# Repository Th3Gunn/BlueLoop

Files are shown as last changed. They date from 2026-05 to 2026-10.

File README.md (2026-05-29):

BluePill devboard based project - ultra compact guitar loop switcher controlled entirely through MIDI TRS (something like Morningstar ML5R).
Includes 0.96" I2C LCD module, few buttons (only for programming), USB-C for flashing and USB MIDI. 
5 relay controlled loops (relays controlled with 74HC595 bit shift register), and discrete MOSFET input and  output mute circuit.

Future plans are to make completely custom board (without BluePill module) and to create Windows application for preset programming.

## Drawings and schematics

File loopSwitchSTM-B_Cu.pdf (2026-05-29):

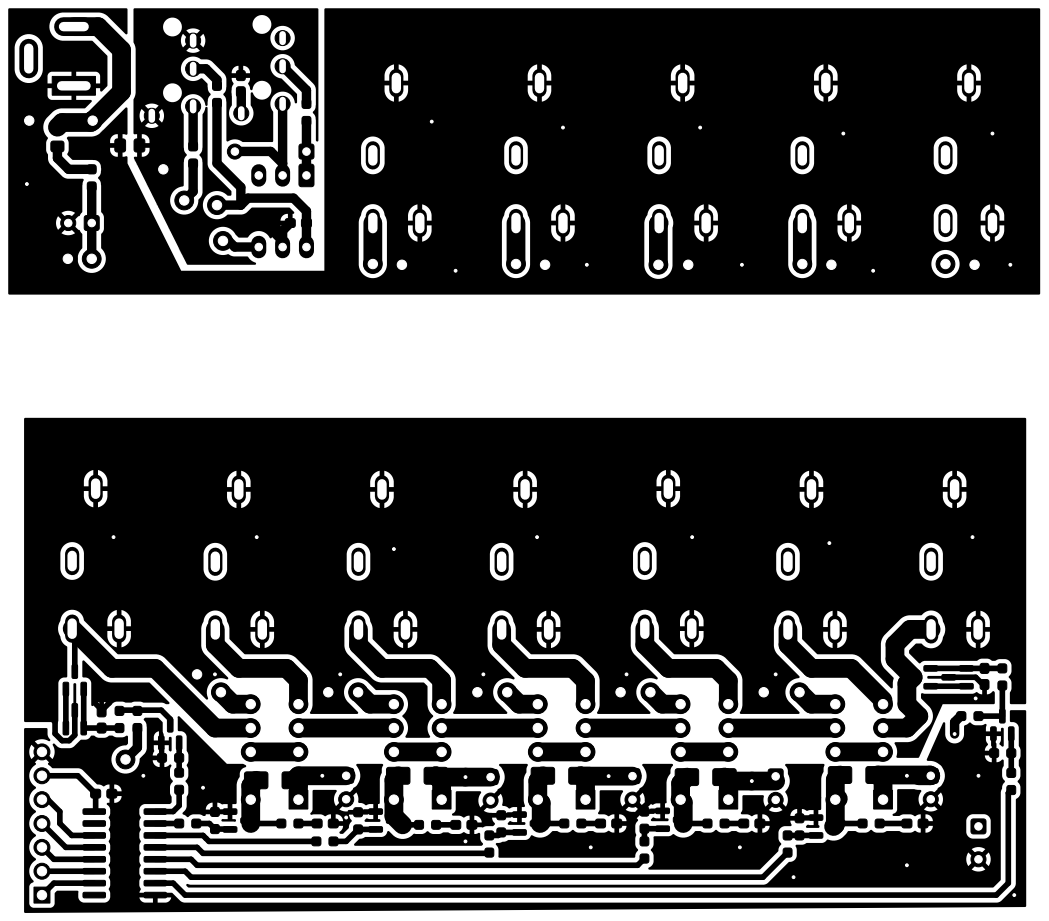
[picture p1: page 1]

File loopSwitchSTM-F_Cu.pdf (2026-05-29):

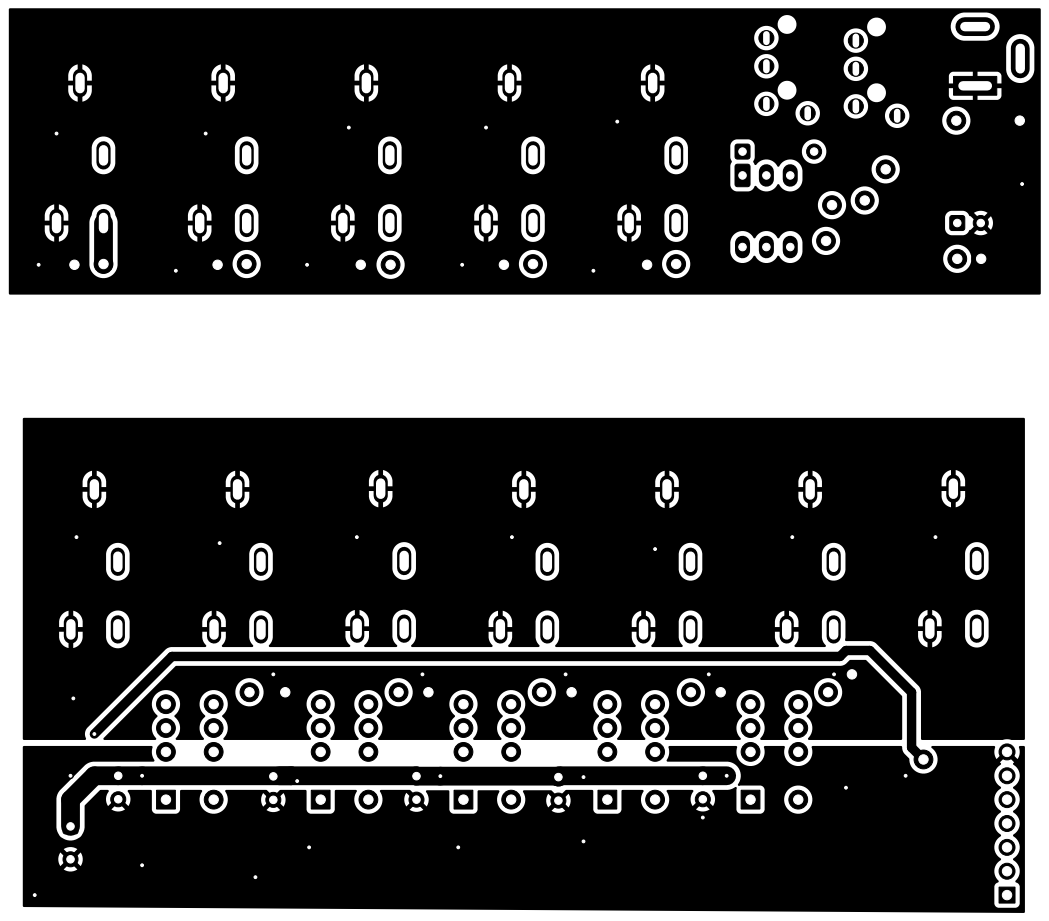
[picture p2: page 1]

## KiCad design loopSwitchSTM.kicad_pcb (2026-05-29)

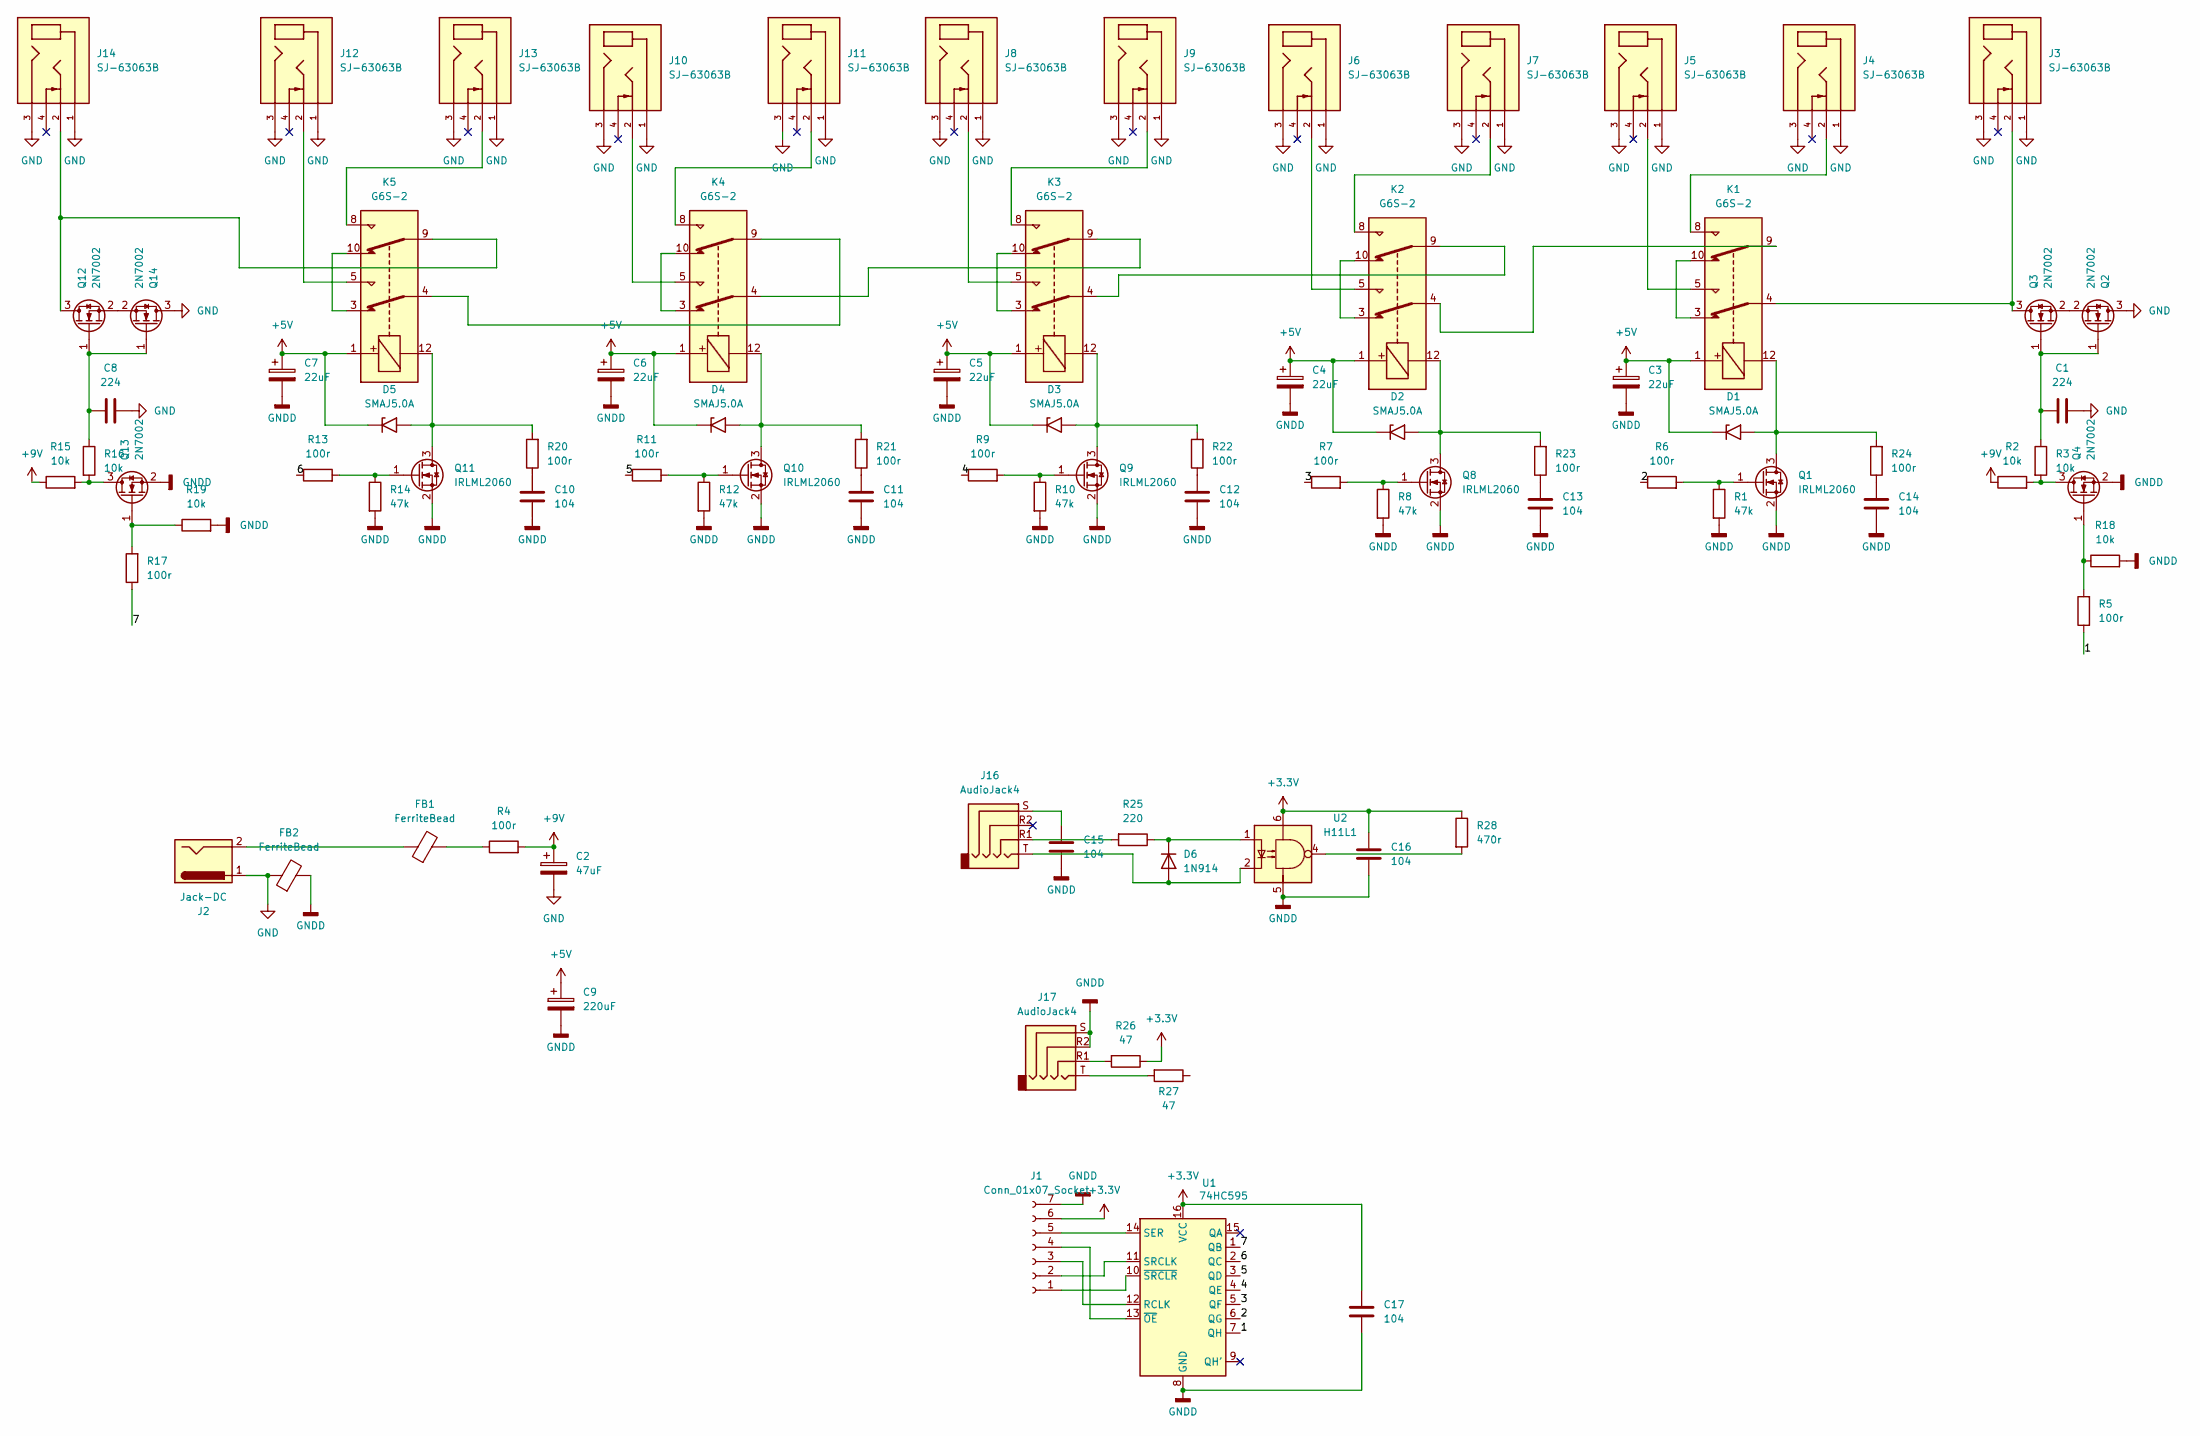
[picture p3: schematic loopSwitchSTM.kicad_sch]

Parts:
C1, C8: 224; C_0603_1608Metric_Pad1.08x0.95mm_HandSolder
C2: 47uF; CP_Radial_D5.0mm_P2.50mm
C3, C4, C5, C6, C7: 22uF; CP_Radial_D5.0mm_P2.50mm
C9: 220uF; CP_Radial_D8.0mm_P3.50mm
C10, C11, C12, C13, C14, C15, C16, C17: 104; C_0603_1608Metric_Pad1.08x0.95mm_HandSolder
D1, D2, D3, D4, D5: SMAJ5.0A; D_SMA
D6: 1N914; D_DO-35_SOD27_P7.62mm_Horizontal
FB1, FB2: FerriteBead; L_0805_2012Metric_Pad1.15x1.40mm_HandSolder
J1: Conn_01x07_Socket; PinHeader_1x07_P2.54mm_Vertical
J2: Jack-DC; BarrelJack_GCT_DCJ200-10-A_Horizontal
J3, J4, J5, J6, J7, J8, J9, J10, J11, J12, J13, J14: SJ-63063B; CUI_SJ-63063B; PARTREV 1.0
J16, J17: AudioJack4; PJ-320A
K1, K2, K3, K4, K5: G6S-2; Relay_DPDT_Omron_G6S-2
Q1, Q8, Q9, Q10, Q11: IRLML2060; SOT-23
Q2, Q3, Q4, Q12, Q13, Q14: 2N7002; SOT-23
R1, R8, R10, R12, R14: 47k; R_0603_1608Metric_Pad0.98x0.95mm_HandSolder
R2, R3, R15, R16, R18, R19: 10k; R_0603_1608Metric_Pad0.98x0.95mm_HandSolder
R4, R5, R6, R7, R9, R11, R13, R17, R20, R21, R22, R23, R24: 100r; R_0603_1608Metric_Pad0.98x0.95mm_HandSolder
R25: 220; R_0603_1608Metric_Pad0.98x0.95mm_HandSolder
R26, R27: 47; R_0603_1608Metric_Pad0.98x0.95mm_HandSolder
R28: 470r
U1: 74HC595; SOIC-16W_5.3x10.2mm_P1.27mm
U2: H11L1; DIP-6_W7.62mm_LongPads

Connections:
+3.3V: C16.2, C17.2, J1.6, R26.1, R28.1, U1.16 (VCC), U2.6
+5V: C3.1, C4.1, C5.1, C6.1, C7.1, C9.1, D1.1 (A1), D2.1 (A1), D3.1 (A1), D4.1 (A1), D5.1 (A1), K1.1, K2.1, K3.1, K4.1, K5.1
+9V: C2.1, R2.1, R4.2, R15.1
/1: R5.1, U1.7 (QH)
/2: R6.1, U1.6 (QG)
/3: R7.1, U1.5 (QF)
/4: R9.1, U1.4 (QE)
/5: R11.1, U1.3 (QD)
/6: R13.1, U1.2 (QC)
/7: R17.1, U1.1 (QB)
GND: C1.2, C2.2, C8.2, FB2.1, J2.1, J3.1, J3.3, J4.1, J4.3, J5.1, J5.3, J6.1, J6.3, J7.1, J7.3, J8.1, J8.3, J9.1, J9.3, J10.1, J10.3, J11.1, J11.3, J12.1, J12.3, J13.1, J13.3, J14.1, J14.3, Q2.3 (D), Q14.3 (D)
GNDD: C3.2, C4.2, C5.2, C6.2, C7.2, C9.2, C10.1, C11.1, C12.1, C13.1, C14.1, C15.1, C16.1, C17.1, FB2.2, J1.7, J17.R2, J17.S, Q1.2 (S), Q4.2 (S), Q8.2 (S), Q9.2 (S), Q10.2 (S), Q11.2 (S), Q13.2 (S), R1.2, R8.2, R10.2, R12.2, R14.2, R18.2, R19.2, U1.8 (GND), U2.5
unnamed: C10.2, R20.1
unnamed: C11.2, R21.1
unnamed: C12.2, R22.1
unnamed: C13.2, R23.1
unnamed: C14.2, R24.1
unnamed: C15.2, J16.S
unnamed: D1.2 (A2), K1.12, Q1.3 (D), R24.2
unnamed: D2.2 (A2), K2.12, Q8.3 (D), R23.2
unnamed: D3.2 (A2), K3.12, Q9.3 (D), R22.2
unnamed: D4.2 (A2), K4.12, Q10.3 (D), R21.2
unnamed: D5.2 (A2), K5.12, Q11.3 (D), R20.2
unnamed: D6.2 (A), J16.T, U2.2
unnamed: D6.1 (K), R25.1, U2.1
unnamed: FB1.1, J2.2
unnamed: FB1.2, R4.1
unnamed: J1.1, U1.10 (~SRCLR)
unnamed: J1.2, U1.11 (SRCLK)
unnamed: J1.3, U1.12 (RCLK)
unnamed: J1.4, U1.13 (~OE)
unnamed: J1.5, U1.14 (SER)
unnamed: J4.2, K1.8
unnamed: J5.2, K1.5
unnamed: J6.2, K2.5
unnamed: J7.2, K2.8
unnamed: J8.2, K3.5
unnamed: J9.2, K3.8
unnamed: J10.2, K4.5
unnamed: J11.2, K4.8
unnamed: J12.2, K5.5
unnamed: J13.2, K5.8
unnamed: J16.R1, R25.2
unnamed: J17.R1, R26.2
unnamed: J17.T, R27.2
unnamed: K1.9, K2.4
unnamed: K1.3, K1.10
unnamed: K2.9, K3.4
unnamed: K2.3, K2.10
unnamed: K3.9, K4.4
unnamed: K3.3, K3.10
unnamed: K4.9, K5.4
unnamed: K4.3, K4.10
unnamed: K5.3, K5.10
unnamed: Q1.1 (G), R1.1, R6.2
unnamed: C1.1, Q2.1 (G), Q3.1 (G), R3.1
unnamed: Q2.2 (S), Q3.2 (S)
unnamed: J3.2, K1.4, Q3.3 (D)
unnamed: Q4.3 (D), R2.2, R3.2
unnamed: Q4.1 (G), R5.2, R18.1
unnamed: Q8.1 (G), R7.2, R8.1
unnamed: Q9.1 (G), R9.2, R10.1
unnamed: Q10.1 (G), R11.2, R12.1
unnamed: Q11.1 (G), R13.2, R14.1
unnamed: J14.2, K5.9, Q12.3 (D)
unnamed: C8.1, Q12.1 (G), Q14.1 (G), R16.1
unnamed: Q12.2 (S), Q14.2 (S)
unnamed: Q13.3 (D), R15.2, R16.2
unnamed: Q13.1 (G), R17.2, R19.1
unnamed: R28.2, U2.4

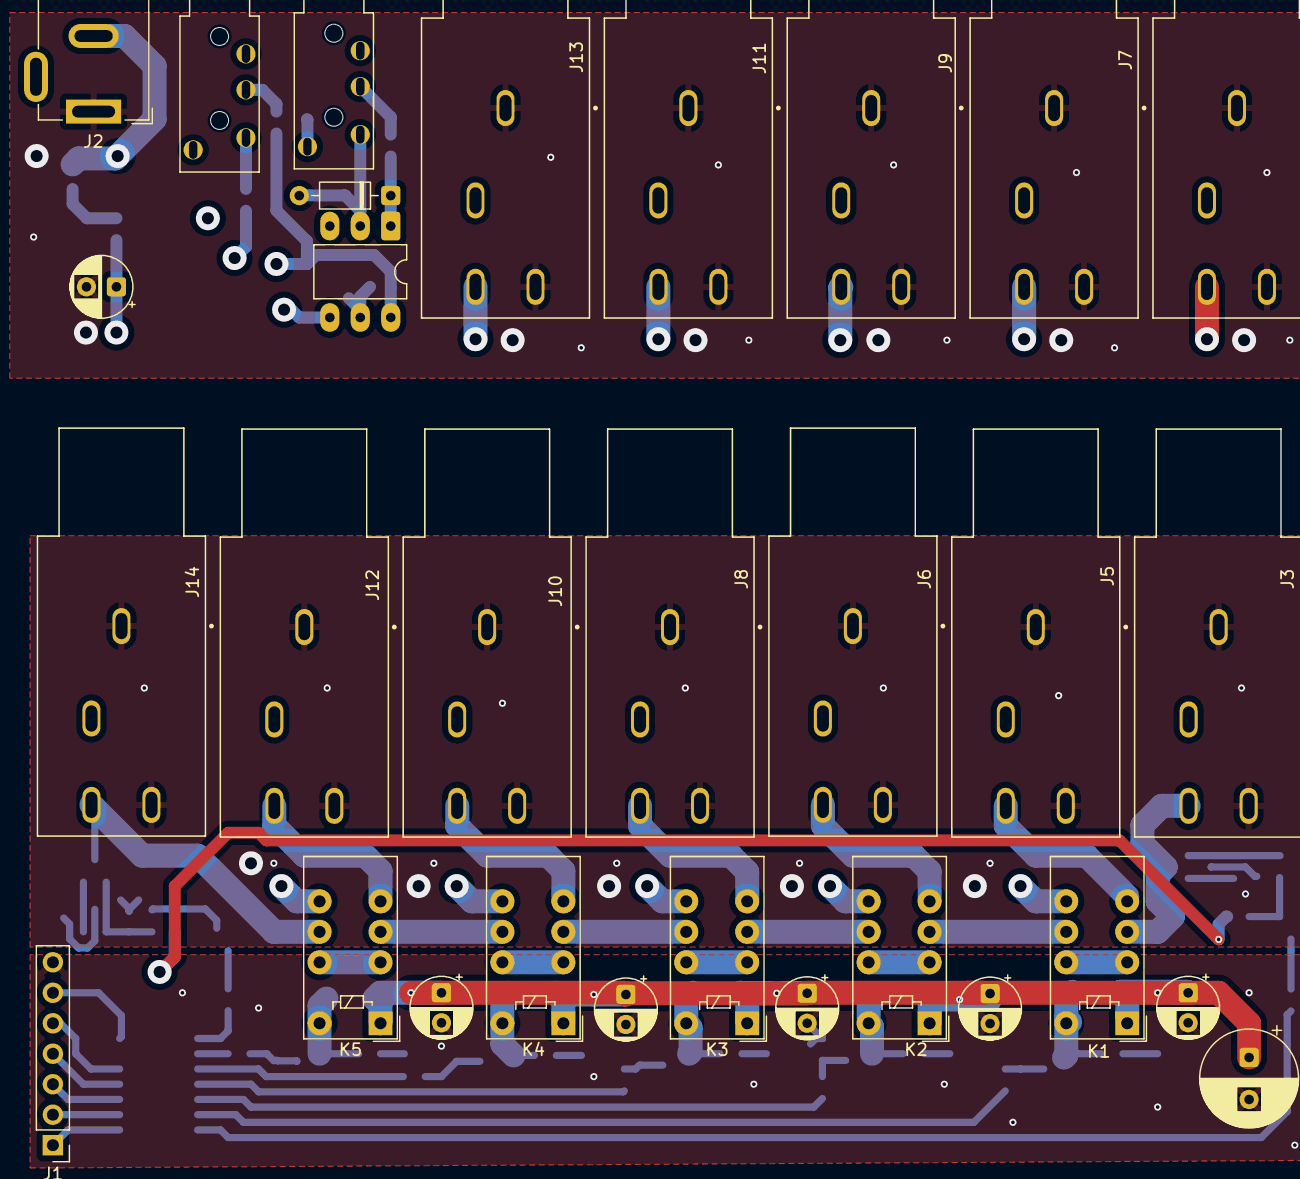
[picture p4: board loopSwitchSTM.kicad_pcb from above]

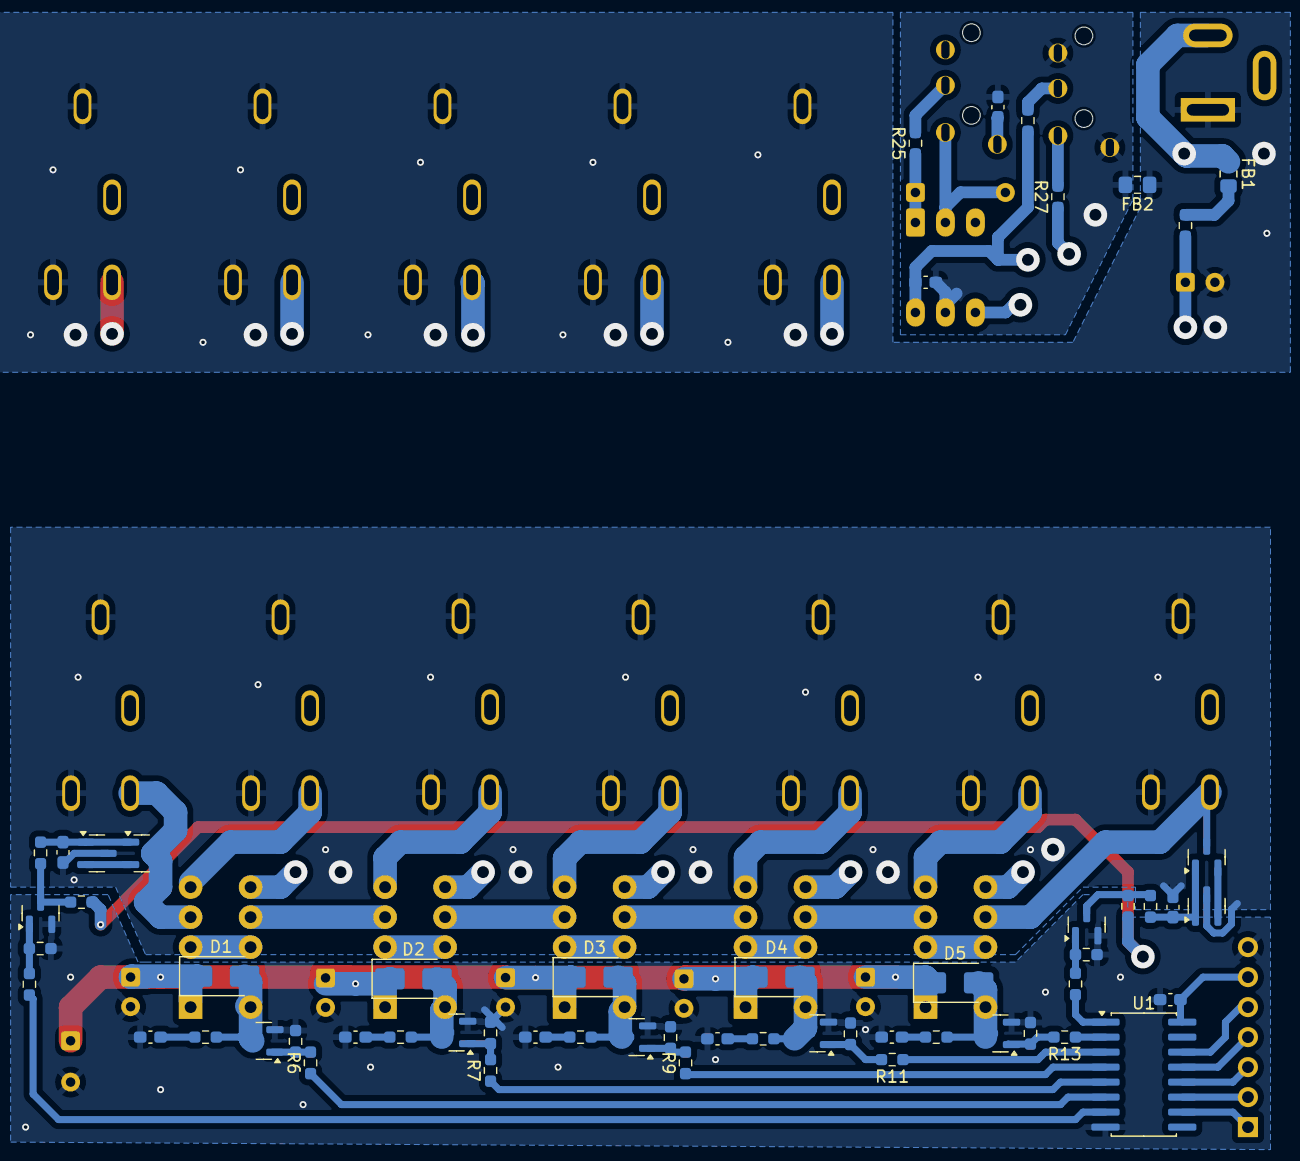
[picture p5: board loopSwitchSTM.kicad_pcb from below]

Board: 2 copper layers, 86 parts (56 on the bottom side), 69 nets.

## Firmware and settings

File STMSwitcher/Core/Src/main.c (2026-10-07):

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
/* Includes ------------------------------------------------------------------*/
#include "main.h"

/* USER CODE BEGIN Includes */
#include <stdio.h>
// NOTE: You must include a standard STM32 HAL SSD1306 library in your project
// (e.g., https://github.com/afaf-buga/stm32-ssd1306)
#include "ssd1306.h"
#include "ssd1306_fonts.h"
/* USER CODE END Includes */

I2C_HandleTypeDef hi2c1;

SPI_HandleTypeDef hspi1;

UART_HandleTypeDef huart1;

PCD_HandleTypeDef hpcd_USB_FS;

/* USER CODE BEGIN PV */
uint8_t midi_rx_byte;
uint8_t current_relay_state = 0x00;
char display_buf[32];
/* USER CODE END PV */

void SystemClock_Config(void);
static void MX_GPIO_Init(void);
static void MX_I2C1_Init(void);
static void MX_SPI1_Init(void);
static void MX_USART1_UART_Init(void);
static void MX_USB_PCD_Init(void);
/* USER CODE BEGIN PFP */
void Update_Relays(uint8_t state);
void MIDI_Process_Byte(uint8_t byte);
/* USER CODE END PFP */

/* USER CODE BEGIN 0 */

/**
 * @brief Sends a byte to the 74HC595 shift register using SPI1
 */
void Update_Relays(uint8_t state)
{
    // Transmit data via SPI (SER -> PA7, SRCLK -> PA5)
    HAL_SPI_Transmit(&hspi1, &state, 1, HAL_MAX_DELAY);

    // Latch the data to the outputs (RCLK -> PA4)
    HAL_GPIO_WritePin(GPIOA, GPIO_PIN_4, GPIO_PIN_SET);
    // Brief delay to ensure latch pin registers high
    for(volatile int i=0; i<100; i++);
    HAL_GPIO_WritePin(GPIOA, GPIO_PIN_4, GPIO_PIN_RESET);
}

/**
 * @brief Basic MIDI parser for Program Change messages
 */
void MIDI_Process_Byte(uint8_t byte)
{
    static uint8_t midi_state = 0;
    static uint8_t status_byte = 0;

    // Check if it's a Status Byte (MSB is 1)
    if (byte >= 0x80)
    {
        status_byte = byte;
        // Check if Program Change (0xCn, where n is channel 0-F)
        if ((status_byte & 0xF0) == 0xC0)
        {
            midi_state = 1; // Expect 1 data byte for PC
        }
        else
        {
            midi_state = 0; // Ignore other messages for now
        }
    }
    // Data byte processing
    else
    {
        if (midi_state == 1 && (status_byte & 0xF0) == 0xC0)
        {
            // Program Change Data Received (Value 0-127)
            current_relay_state = byte;
            Update_Relays(current_relay_state); // Set relays directly to PC value for test

            // Update OLED Display
            ssd1306_Fill(Black);
            ssd1306_SetCursor(2, 10);
            ssd1306_WriteString("MIDI PC Received", Font_7x10, White);

            sprintf(display_buf, "Preset: %d", byte);
            ssd1306_SetCursor(2, 35);
            ssd1306_WriteString(display_buf, Font_11x18, White);
            ssd1306_UpdateScreen();

            midi_state = 0; // Reset state machine
        }
    }
}

/**
 * @brief UART RX Interrupt Callback
 */
void HAL_UART_RxCpltCallback(UART_HandleTypeDef *huart)
{
    if (huart->Instance == USART1)
    {
        // Process incoming MIDI byte
        MIDI_Process_Byte(midi_rx_byte);
        // Start listening for the next byte
        HAL_UART_Receive_IT(&huart1, &midi_rx_byte, 1);
    }
}
/* USER CODE END 0 */

/**
  * @brief  The application entry point.
  * @retval int
  */
int main(void)
{

  /* MCU Configuration--------------------------------------------------------*/

  /* Reset of all peripherals, Initializes the Flash interface and the Systick. */
  HAL_Init();

  /* Configure the system clock */
  SystemClock_Config();

  /* Initialize all configured peripherals */
  MX_GPIO_Init();
  MX_I2C1_Init();
  MX_SPI1_Init();
  MX_USART1_UART_Init();
  MX_USB_PCD_Init();
  /* USER CODE BEGIN 2 */

  // Set default states for 74HC595 control pins
  HAL_GPIO_WritePin(GPIOA, GPIO_PIN_3, GPIO_PIN_SET);   // SRCLR HIGH: Do not clear shift register
  HAL_GPIO_WritePin(GPIOB, GPIO_PIN_0, GPIO_PIN_RESET); // OE LOW: Enable outputs
  HAL_GPIO_WritePin(GPIOA, GPIO_PIN_4, GPIO_PIN_RESET); // RCLK LOW: Default latch state

  // Clear relays on boot
  Update_Relays(0x00);

  // Initialize OLED
  ssd1306_Init();
  ssd1306_Fill(Black);
  ssd1306_SetCursor(10, 20);
  ssd1306_WriteString("MIDI Looper", Font_11x18, White);
  ssd1306_SetCursor(10, 45);
  ssd1306_WriteString("Waiting...", Font_7x10, White);
  ssd1306_UpdateScreen();

  // Start UART Interrupt Reception for MIDI
  HAL_UART_Receive_IT(&huart1, &midi_rx_byte, 1);

  /* USER CODE END 2 */

  /* Infinite loop */
  /* USER CODE BEGIN WHILE */
  while (1)
  {
    /* USER CODE END WHILE */

    /* USER CODE BEGIN 3 */

    /*
     * --- UNCOMMENT THIS BLOCK TO TEST RELAYS & OLED WITHOUT MIDI ---
     * Cycles through relays one by one every 1 second
     */

    /*
    static uint8_t test_val = 1;
    Update_Relays(test_val);

    sprintf(display_buf, "Relay: %02X", test_val);
    ssd1306_Fill(Black);
    ssd1306_SetCursor(10, 30);
    ssd1306_WriteString(display_buf, Font_11x18, White);
    ssd1306_UpdateScreen();

    test_val = (test_val << 1);
    if(test_val == 0) test_val = 1; // Reset after 8th bit

    HAL_Delay(1000);
    */

  }
  /* USER CODE END 3 */
}

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


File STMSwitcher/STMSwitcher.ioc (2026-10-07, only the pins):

Mcu.UserName=STM32F103C8Tx
PA10.Signal=USART1_RX
PA11.Signal=USB_DM
PA12.Signal=USB_DP
PA3.Signal=GPIO_Output
PA4.Signal=GPIO_Output
PA5.Signal=SPI1_SCK
PA7.Signal=SPI1_MOSI
PA9.Signal=USART1_TX
PB0.Signal=GPIO_Output
PB6.Signal=I2C1_SCL
PB7.Signal=I2C1_SDA
PD0-OSC_IN.Signal=RCC_OSC_IN
PD1-OSC_OUT.Signal=RCC_OSC_OUT

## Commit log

2026-05-29 PCB rev 0.1
    [loopSwitchSTM.kicad_pcb, loopSwitchSTM.kicad_sch]
2026-05-29 Add README content for BluePill project
    Add project description for BluePill guitar loop switcher.
2026-05-29 Update README with future project plans
    Added future plans for custom board and Windows application.
2026-05-29 Update future plans for custom board design

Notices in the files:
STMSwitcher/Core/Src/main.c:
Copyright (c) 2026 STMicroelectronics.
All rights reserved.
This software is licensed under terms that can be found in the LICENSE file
